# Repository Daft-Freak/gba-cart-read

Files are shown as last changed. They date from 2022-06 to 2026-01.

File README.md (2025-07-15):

# GBA Cartridge Reader

Hardware and software for an RP2xxx-based Game Boy and Game Boy Advance cartridge reader that presents the contents as a USB storage device.

## Board
- `board` contains the "v1" PGA2040-based GBA-only board
- `board-v4` contains the new RP2350-based design that also supports Game Boy carts and can _theoretically_ be expanded. (to be added when I make the fixed version)
- (v2/3 designs were never made. For completeness v2 added the Game Boy support, and v3 was a custom RP2040 design)

## Case

- "v1": https://www.printables.com/model/972096-gba-cartridge-reader-case

## Software
For the old RP2040-based boards, just build like any other pico-sdk based project. For the RP2350-based board configure with `cmake -DPICO_BOARD=pico2 -DPICO_RP2350A=0 [...]`.

### Tested GBA carts
 - 8K EEPROM
 - 32k SRAM
 - 64k flash
 - 128k flash

### Tested GB/GBC carts (v4)
 - No MBC
 - MBC1 (<= 512k ROM / 8k RAM)
 - MBC2
 - MBC3
 - MBC5
 - MBC7 (256 byte EEPROM)

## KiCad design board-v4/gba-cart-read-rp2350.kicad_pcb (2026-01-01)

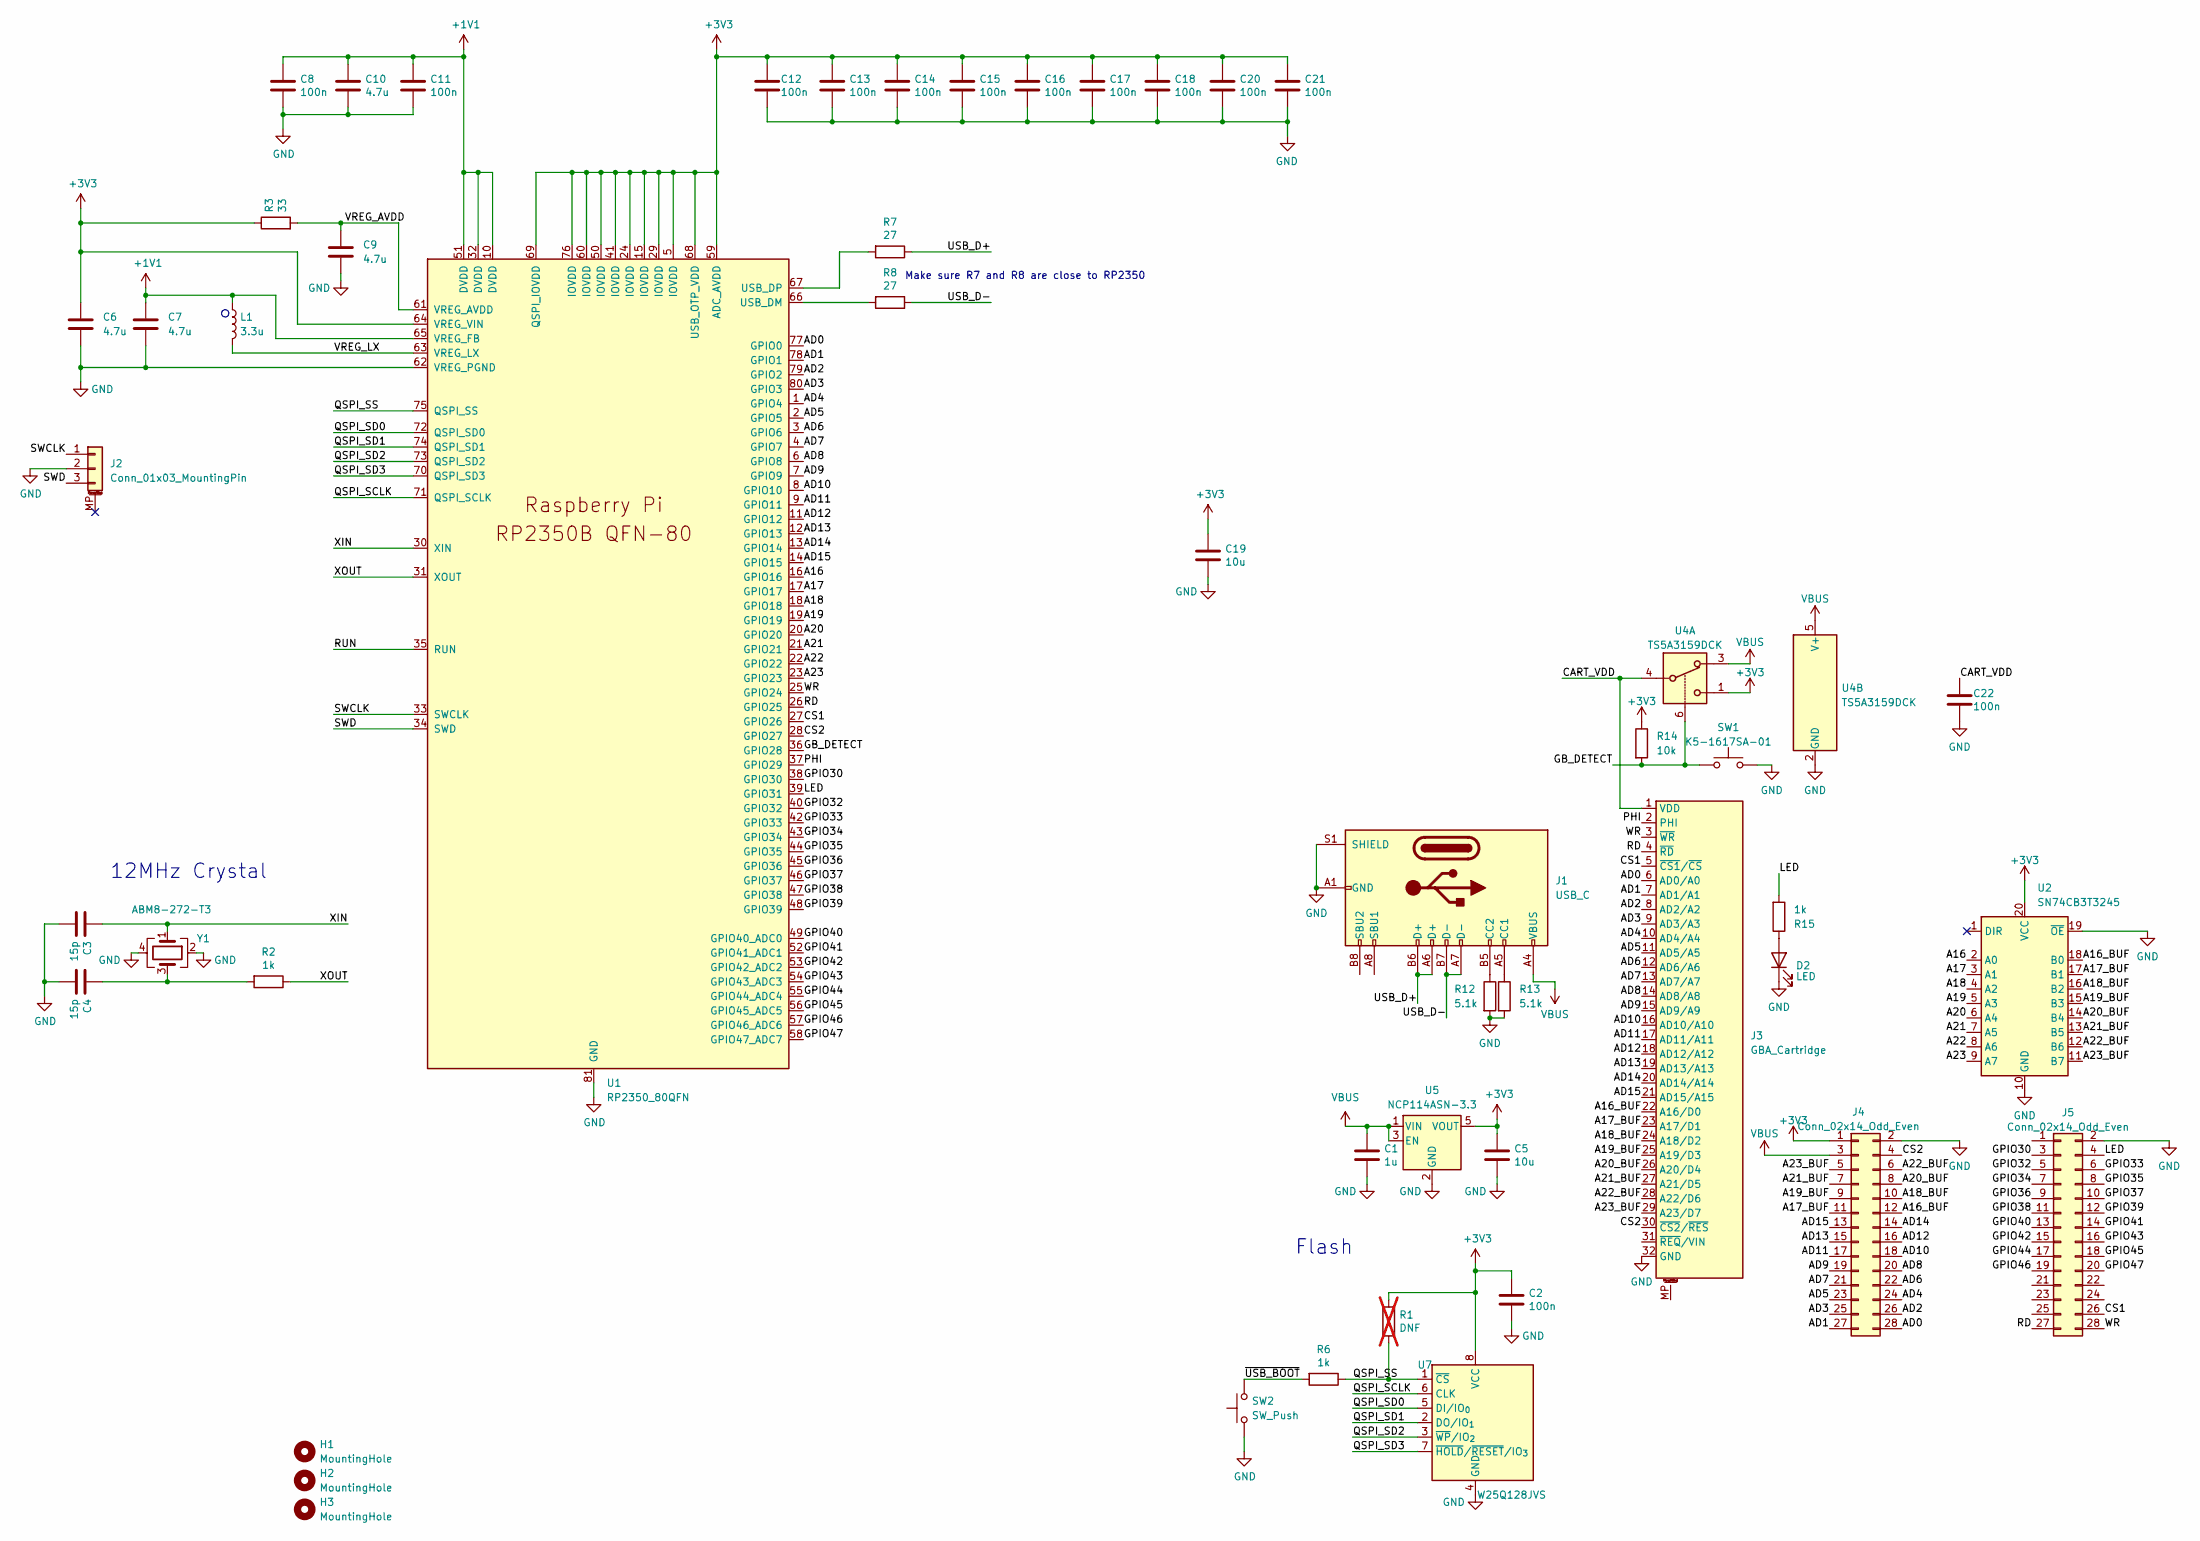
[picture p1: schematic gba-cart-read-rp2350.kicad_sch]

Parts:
C1: 1u; C_0805_2012Metric
C2, C8, C11, C12, C13, C14, C15, C16, C17, C18, C20, C21, C22: 100n; C_0402_1005Metric
C3, C4: 15p; C_0402_1005Metric
C5, C19: 10u; C_0805_2012Metric
C6, C7: 4.7u; C_0402_1005Metric_small_pads
C9, C10: 4.7u; C_0402_1005Metric
D2: LED; LED_0603_1608Metric
H1, H2, H3: MountingHole; MountingHole_2.7mm_M2.5
J1: USB_C; USB_C_Receptacle_HRO_TYPE-C-31-M-12
J2: Conn_01x03_MountingPin; JST_SH_SM03B-SRSS-TB_1x03-1MP_P1.00mm_Horizontal
J3: GBA_Cartridge; GameBoy_Cartridge_AGS_1x32-1MP_P1.50mm_Socket_Horizontal
J4, J5: Conn_02x14_Odd_Even; PinHeader_2x14_P2.54mm_Vertical
L1: 3.3u; L_pol_2016
R1: DNF; C_0402_1005Metric; not fitted
R2, R6, R15: 1k; R_0402_1005Metric
R3: 33; R_0402_1005Metric
R7, R8: 27; R_0402_1005Metric
R12, R13: 5.1k; R_0402_1005Metric
R14: 10k; R_0402_1005Metric
SW1: K5-1617SA-01
SW2: SW_Push; SW_Push_1P1T_XKB_TS-1187A
U1: RP2350_80QFN; RP2350-QFN-80-1EP_10x10_P0.4mm_EP3.4x3.4mm_ThermalVias
U2: SN74CB3T3245; TSSOP-20_4.4x6.5mm_P0.65mm
U4: TS5A3159DCK; SOT-363_SC-70-6
U5: NCP114ASN-3.3; TSOP-5_1.65x3.05mm_P0.95mm
U7: W25Q128JVS; SOIC-8_5.3x5.3mm_P1.27mm
Y1: ABM8-272-T3; Crystal_SMD_3225-4Pin_3.2x2.5mm

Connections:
+1V1: C7.1, C8.1, C10.1, C11.1, L1.1, U1.10 (DVDD), U1.32 (DVDD), U1.51 (DVDD), U1.65 (VREG_FB)
+3V3: C2.1, C5.1, C6.1, C12.1, C13.1, C14.1, C15.1, C16.1, C17.1, C18.1, C19.1, C20.1, C21.1, J4.1, R1.1, R3.1, R14.1, U1.5 (IOVDD), U1.15 (IOVDD), U1.24 (IOVDD), U1.29 (IOVDD), U1.41 (IOVDD), U1.50 (IOVDD), U1.59 (ADC_AVDD), U1.60 (IOVDD), U1.64 (VREG_VIN), U1.68 (USB_OTP_VDD), U1.69 (QSPI_IOVDD), U1.76 (IOVDD), U2.20 (VCC), U4.1, U5.5 (VOUT), U7.8 (VCC)
/A16: U1.16 (GPIO16), U2.2 (A0)
/A16_BUF: J3.22 (A16/D0), J4.12, U2.18 (B0)
/A17: U1.17 (GPIO17), U2.3 (A1)
/A17_BUF: J3.23 (A17/D1), J4.11, U2.17 (B1)
/A18: U1.18 (GPIO18), U2.4 (A2)
/A18_BUF: J3.24 (A18/D2), J4.10, U2.16 (B2)
/A19: U1.19 (GPIO19), U2.5 (A3)
/A19_BUF: J3.25 (A19/D3), J4.9, U2.15 (B3)
/A20: U1.20 (GPIO20), U2.6 (A4)
/A20_BUF: J3.26 (A20/D4), J4.8, U2.14 (B4)
/A21: U1.21 (GPIO21), U2.7 (A5)
/A21_BUF: J3.27 (A21/D5), J4.7, U2.13 (B5)
/A22: U1.22 (GPIO22), U2.8 (A6)
/A22_BUF: J3.28 (A22/D6), J4.6, U2.12 (B6)
/A23: U1.23 (GPIO23), U2.9 (A7)
/A23_BUF: J3.29 (A23/D7), J4.5, U2.11 (B7)
/AD0: J3.6 (AD0/A0), J4.28, U1.77 (GPIO0)
/AD1: J3.7 (AD1/A1), J4.27, U1.78 (GPIO1)
/AD2: J3.8 (AD2/A2), J4.26, U1.79 (GPIO2)
/AD3: J3.9 (AD3/A3), J4.25, U1.80 (GPIO3)
/AD4: J3.10 (AD4/A4), J4.24, U1.1 (GPIO4)
/AD5: J3.11 (AD5/A5), J4.23, U1.2 (GPIO5)
/AD6: J3.12 (AD6/A6), J4.22, U1.3 (GPIO6)
/AD7: J3.13 (AD7/A7), J4.21, U1.4 (GPIO7)
/AD8: J3.14 (AD8/A8), J4.20, U1.6 (GPIO8)
/AD9: J3.15 (AD9/A9), J4.19, U1.7 (GPIO9)
/AD10: J3.16 (AD10/A10), J4.18, U1.8 (GPIO10)
/AD11: J3.17 (AD11/A11), J4.17, U1.9 (GPIO11)
/AD12: J3.18 (AD12/A12), J4.16, U1.11 (GPIO12)
/AD13: J3.19 (AD13/A13), J4.15, U1.12 (GPIO13)
/AD14: J3.20 (AD14/A14), J4.14, U1.13 (GPIO14)
/AD15: J3.21 (AD15/A15), J4.13, U1.14 (GPIO15)
/CART_VDD: C22.1, J3.1 (VDD), U4.4
/CS1: J3.5 (~CS1/~CS), J5.26, U1.27 (GPIO26)
/CS2: J3.30 (~CS2/~RES), J4.4, U1.28 (GPIO27)
/GB_DETECT: R14.2, SW1.2, U1.36 (GPIO28), U4.6
/GPIO30: J5.3, U1.38 (GPIO30)
/GPIO32: J5.5, U1.40 (GPIO32)
/GPIO33: J5.6, U1.42 (GPIO33)
/GPIO34: J5.7, U1.43 (GPIO34)
/GPIO35: J5.8, U1.44 (GPIO35)
/GPIO36: J5.9, U1.45 (GPIO36)
/GPIO37: J5.10, U1.46 (GPIO37)
/GPIO38: J5.11, U1.47 (GPIO38)
/GPIO39: J5.12, U1.48 (GPIO39)
/GPIO40: J5.13, U1.49 (GPIO40_ADC0)
/GPIO41: J5.14, U1.52 (GPIO41_ADC1)
/GPIO42: J5.15, U1.53 (GPIO42_ADC2)
/GPIO43: J5.16, U1.54 (GPIO43_ADC3)
/GPIO44: J5.17, U1.55 (GPIO44_ADC4)
/GPIO45: J5.18, U1.56 (GPIO45_ADC5)
/GPIO46: J5.19, U1.57 (GPIO46_ADC6)
/GPIO47: J5.20, U1.58 (GPIO47_ADC7)
/LED: J5.4, R15.2, U1.39 (GPIO31)
/PHI: J3.2 (PHI), U1.37 (GPIO29)
/QSPI_SCLK: U1.71 (QSPI_SCLK), U7.6 (CLK)
/QSPI_SD0: U1.72 (QSPI_SD0), U7.5 (DI/IO_{0})
/QSPI_SD1: U1.74 (QSPI_SD1), U7.2 (DO/IO_{1})
/QSPI_SD2: U1.73 (QSPI_SD2), U7.3 (~WP/IO_{2})
/QSPI_SD3: U1.70 (QSPI_SD3), U7.7 (~HOLD/~RESET/IO_{3})
/QSPI_SS: R1.2, R6.1, U1.75 (QSPI_SS), U7.1 (~CS)
/RD: J3.4 (~RD), J5.27, U1.26 (GPIO25)
/RUN: U1.35 (RUN)
/SWCLK: J2.1, U1.33 (SWCLK)
/SWD: J2.3, U1.34 (SWD)
/USB_D+: J1.A6 (D+), J1.B6 (D+), R7.1
/USB_D-: J1.A7 (D-), J1.B7 (D-), R8.1
/VREG_AVDD: C9.1, R3.2, U1.61 (VREG_AVDD)
/VREG_LX: L1.2, U1.63 (VREG_LX)
/WR: J3.3 (~WR), J5.28, U1.25 (GPIO24)
/XIN: C3.1, U1.30 (XIN), Y1.1
/XOUT: R2.1, U1.31 (XOUT)
/~USB_BOOT: R6.2, SW2.2
GND: C1.2, C2.2, C3.2, C4.2, C5.2, C6.2, C7.2, C8.2, C9.2, C10.2, C11.2, C12.2, C13.2, C14.2, C15.2, C16.2, C17.2, C18.2, C19.2, C20.2, C21.2, C22.2, D2.1 (K), J1.A1 (GND), J1.A12 (GND), J1.B1 (GND), J1.B12 (GND), J1.S1 (SHIELD), J2.2, J3.32 (GND), J4.2, J5.2, R12.2, R13.2, SW1.1, SW2.1, U1.62 (VREG_PGND), U1.81 (GND), U2.10 (GND), U2.19 (~OE), U4.2 (GND), U5.2 (GND), U7.4 (GND), Y1.2, Y1.4
unnamed: C4.1, R2.2, Y1.3
unnamed: D2.2 (A), R15.1
unnamed: J1.A5 (CC1), R13.1
unnamed: J1.B5 (CC2), R12.1
unnamed: R8.2, U1.66 (USB_DM)
unnamed: R7.2, U1.67 (USB_DP)
VBUS: C1.1, J1.A4 (VBUS), J1.A9 (VBUS), J1.B4 (VBUS), J1.B9 (VBUS), J4.3, U4.3, U4.5 (V+), U5.1 (VIN), U5.3 (EN)

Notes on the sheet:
12MHz Crystal
Flash
Make sure R7 and R8 are close to RP2350

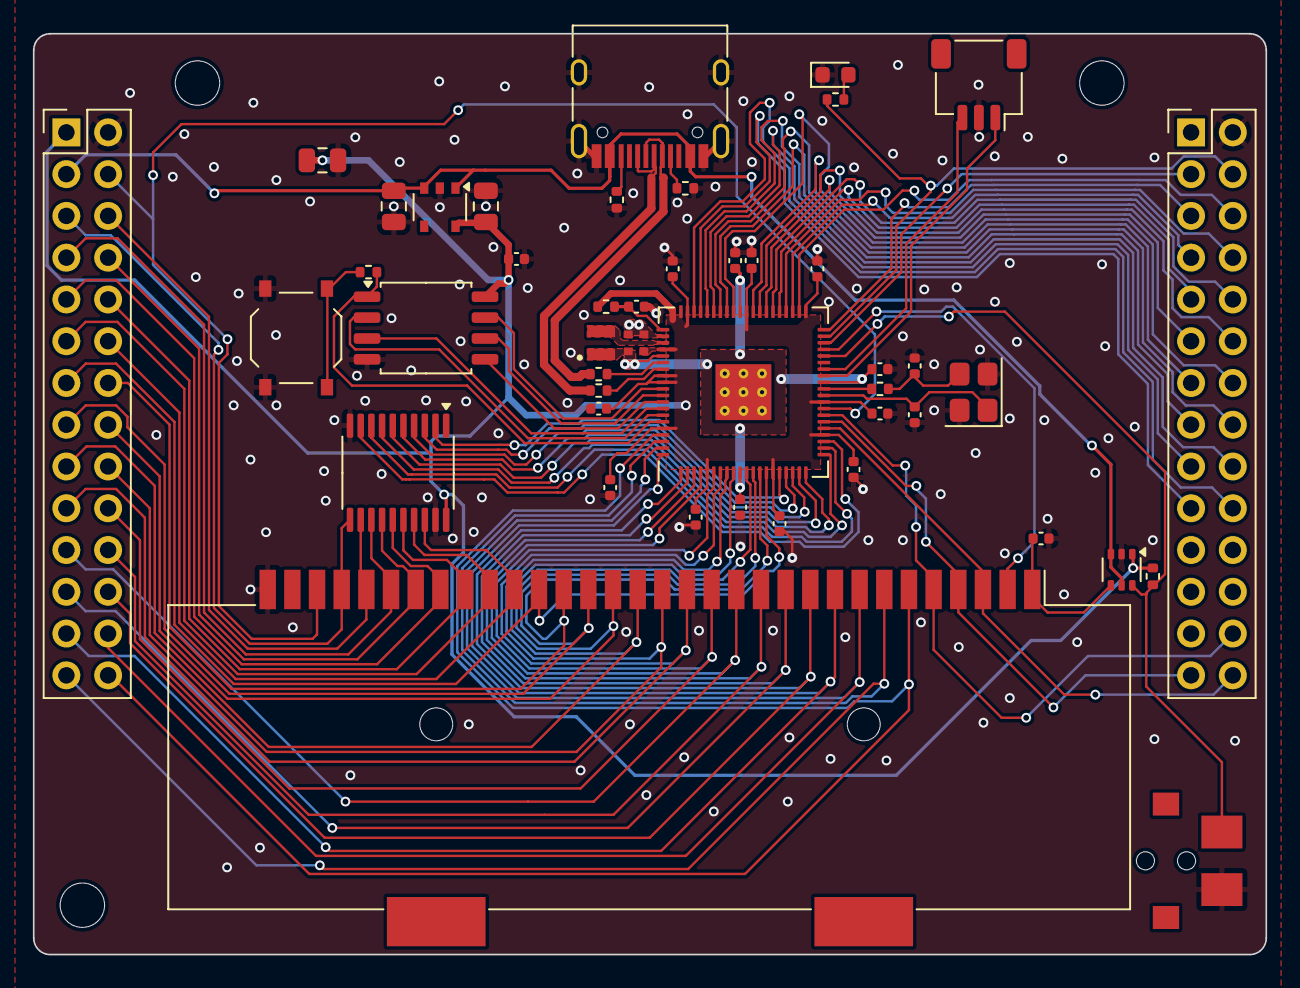
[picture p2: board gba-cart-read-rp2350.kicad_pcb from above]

Board: 2 copper layers, 75.0 x 56.0 mm, 49 parts (0 on the bottom side), 82 nets.

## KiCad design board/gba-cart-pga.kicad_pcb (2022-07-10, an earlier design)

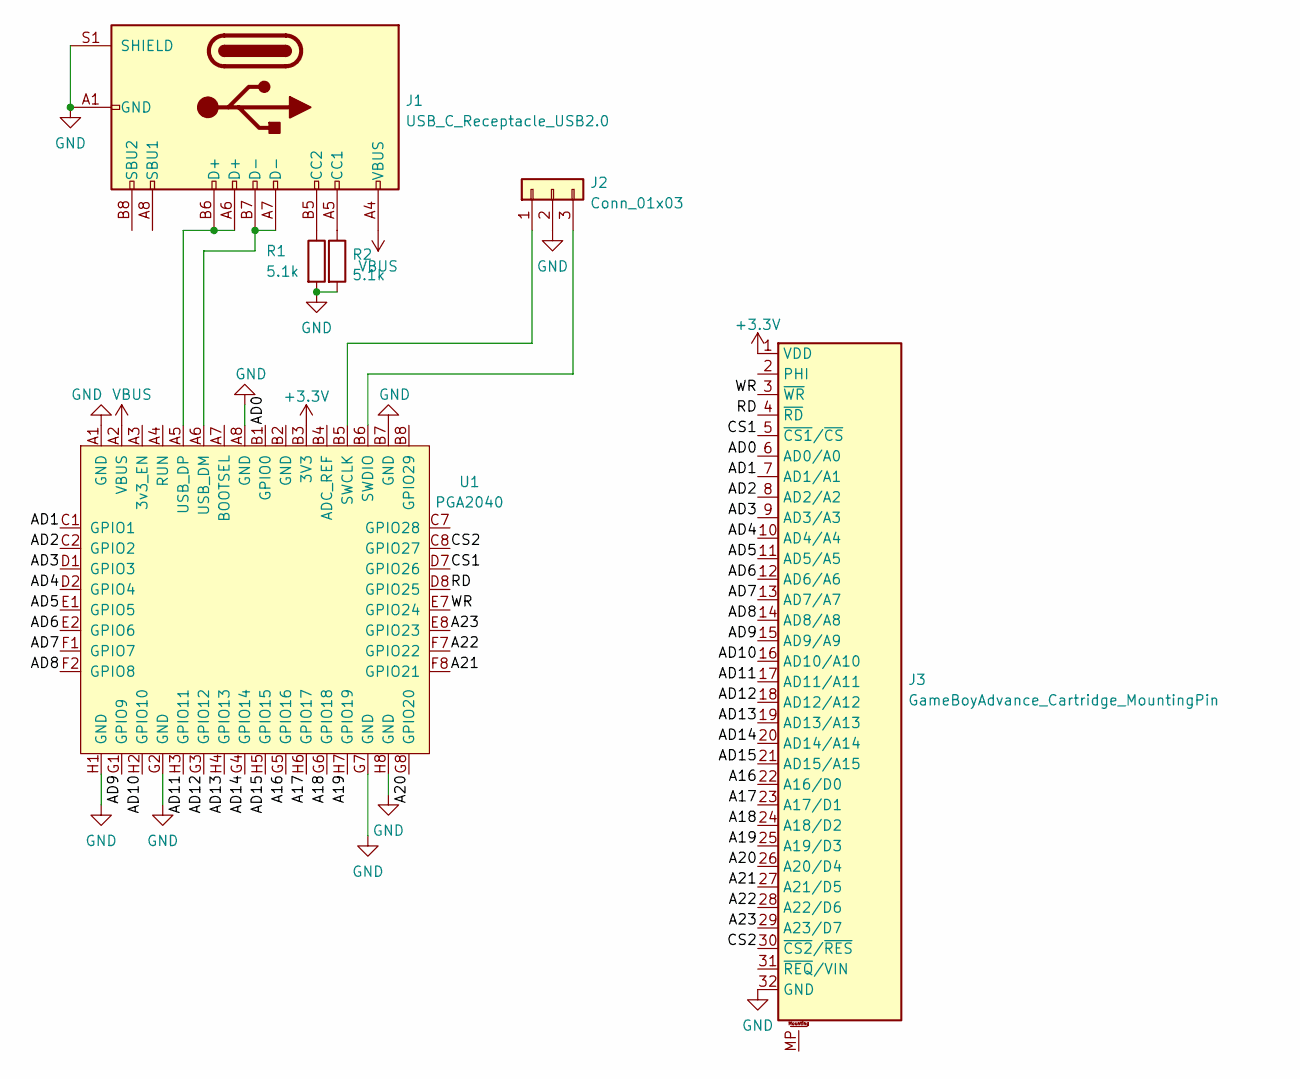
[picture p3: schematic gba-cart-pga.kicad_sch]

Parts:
J1: USB_C_Receptacle_USB2.0; USB_C_Receptacle_XKB_U262-16XN-4BVC11
J2: Conn_01x03; PinHeader_1x03_P2.54mm_Vertical
J3: GameBoyAdvance_Cartridge_MountingPin; GameBoy_Cartridge_AGS_1x32-1MP_P1.50mm_Socket_Horizontal
R1, R2: 5.1k; R_0805_2012Metric_Pad1.20x1.40mm_HandSolder
U1: PGA2040; PGA2040_PTH_NO_SLOT

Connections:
+3V3: J3.1 (VDD), U1.B3 (3V3)
/A16: J3.22 (A16/D0), U1.G5 (GPIO16)
/A17: J3.23 (A17/D1), U1.H6 (GPIO17)
/A18: J3.24 (A18/D2), U1.G6 (GPIO18)
/A19: J3.25 (A19/D3), U1.H7 (GPIO19)
/A20: J3.26 (A20/D4), U1.G8 (GPIO20)
/A21: J3.27 (A21/D5), U1.F8 (GPIO21)
/A22: J3.28 (A22/D6), U1.F7 (GPIO22)
/A23: J3.29 (A23/D7), U1.E8 (GPIO23)
/AD0: J3.6 (AD0/A0), U1.B1 (GPIO0)
/AD1: J3.7 (AD1/A1), U1.C1 (GPIO1)
/AD2: J3.8 (AD2/A2), U1.C2 (GPIO2)
/AD3: J3.9 (AD3/A3), U1.D1 (GPIO3)
/AD4: J3.10 (AD4/A4), U1.D2 (GPIO4)
/AD5: J3.11 (AD5/A5), U1.E1 (GPIO5)
/AD6: J3.12 (AD6/A6), U1.E2 (GPIO6)
/AD7: J3.13 (AD7/A7), U1.F1 (GPIO7)
/AD8: J3.14 (AD8/A8), U1.F2 (GPIO8)
/AD9: J3.15 (AD9/A9), U1.G1 (GPIO9)
/AD10: J3.16 (AD10/A10), U1.H2 (GPIO10)
/AD11: J3.17 (AD11/A11), U1.H3 (GPIO11)
/AD12: J3.18 (AD12/A12), U1.G3 (GPIO12)
/AD13: J3.19 (AD13/A13), U1.H4 (GPIO13)
/AD14: J3.20 (AD14/A14), U1.G4 (GPIO14)
/AD15: J3.21 (AD15/A15), U1.H5 (GPIO15)
/CS1: J3.5 (~CS1/~CS), U1.D7 (GPIO26)
/CS2: J3.30 (~CS2/~RES), U1.C8 (GPIO27)
/RD: J3.4 (~RD), U1.D8 (GPIO25)
/WR: J3.3 (~WR), U1.E7 (GPIO24)
GND: J1.A1 (GND), J1.A12 (GND), J1.B1 (GND), J1.B12 (GND), J1.S1 (SHIELD), J2.2, J3.32 (GND), R1.2, R2.2, U1.A1 (GND), U1.A8 (GND), U1.B7 (GND), U1.G2 (GND), U1.G7 (GND), U1.H1 (GND), U1.H8 (GND)
unnamed: J1.A5 (CC1), R2.1
unnamed: J1.A6 (D+), J1.B6 (D+), U1.A5 (USB_DP)
unnamed: J1.A7 (D-), J1.B7 (D-), U1.A6 (USB_DM)
unnamed: J1.B5 (CC2), R1.1
unnamed: J2.1, U1.B5 (SWCLK)
unnamed: J2.3, U1.B6 (SWDIO)
VBUS: J1.A4 (VBUS), J1.A9 (VBUS), J1.B4 (VBUS), J1.B9 (VBUS), U1.A2 (VBUS)

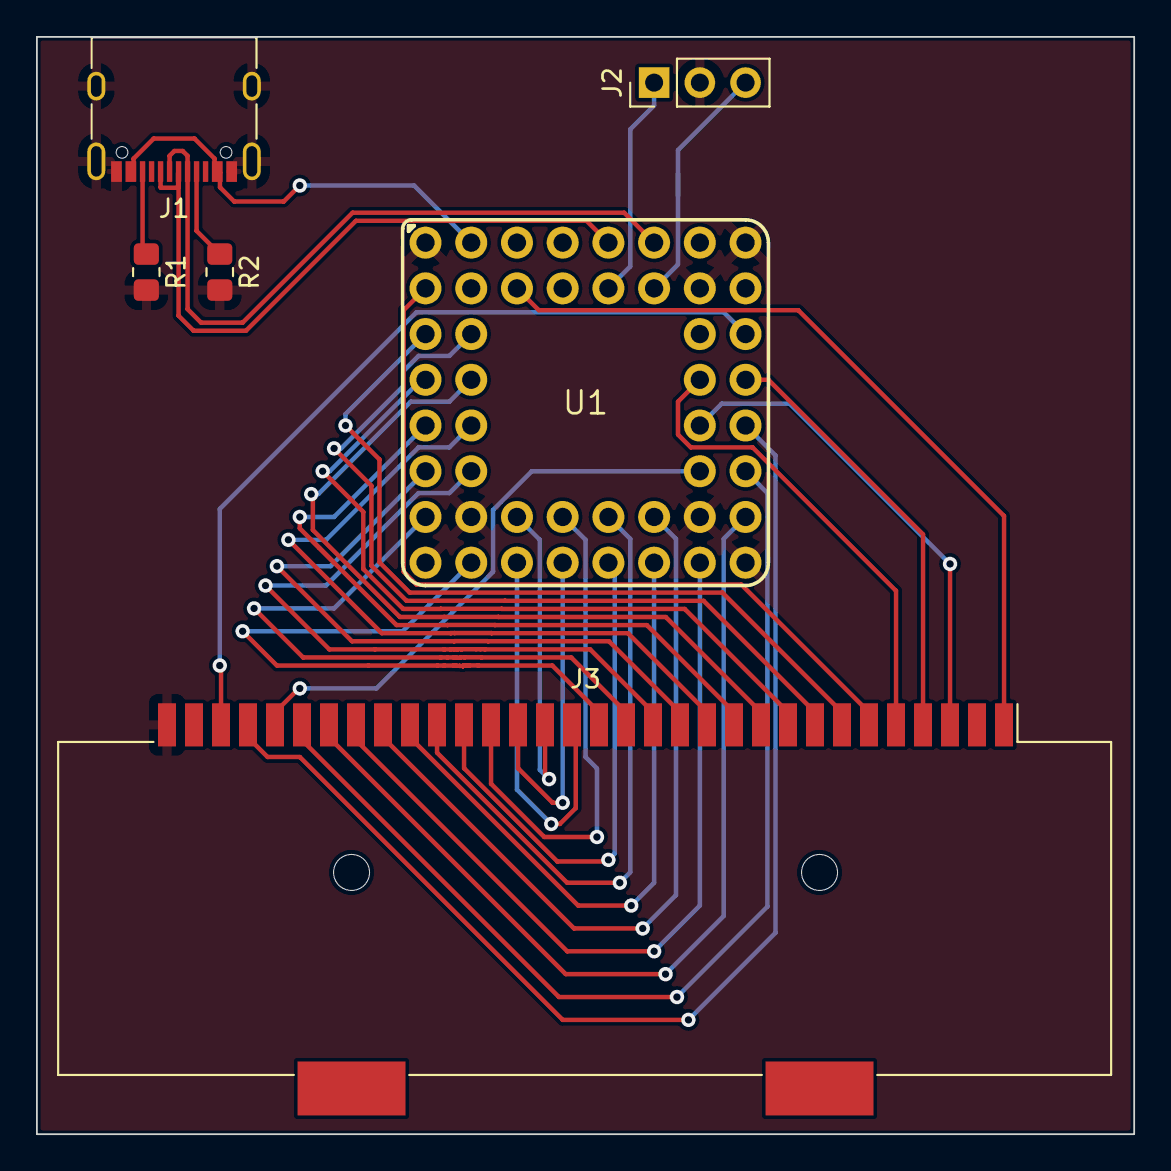
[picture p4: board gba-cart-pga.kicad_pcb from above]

Board: 2 copper layers, 61.0 x 61.0 mm, 6 parts (0 on the bottom side), 37 nets.

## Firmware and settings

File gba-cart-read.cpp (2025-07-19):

#include <algorithm>

#include "pico/stdlib.h"
#include "pico/time.h"
#include "tusb.h"

#include "cartridge.hpp"
#include "filesystem.hpp"

#ifdef PICO_RP2350
#define GB_DETECT_PIN 28
#define STATUS_LED_PIN 31
#endif

static char curGameCode[4]{0};

// GBA
static Cartridge::SaveType saveType = Cartridge::SaveType::Unknown;

// DMG
static Cartridge::MBCType mbcType = Cartridge::MBCType::None;

static void statusSet(bool value)
{
#ifdef STATUS_LED_PIN
    gpio_put(STATUS_LED_PIN, !value);
#endif
}

static void statusToggle()
{
#ifdef STATUS_LED_PIN
    gpio_xor_mask64(1 << STATUS_LED_PIN);
#endif
}

static absolute_time_t ABSOLUTE_TIME_INITIALIZED_VAR(lastAccessBlinkTime, 0);

static void blinkLEDForAccess()
{
    auto time = get_absolute_time();
    if(absolute_time_diff_us(lastAccessBlinkTime, time) > 80000)
    {
        statusToggle();
        lastAccessBlinkTime = time;
    }
}

static void readDMGROM(uint32_t offset, uint32_t len, uint8_t *buf)
{
    // blink while reading
    blinkLEDForAccess();

    if(mbcType == Cartridge::MBCType::None)
        Cartridge::readDMG(offset, buf, len);
    else if(mbcType == Cartridge::MBCType::MBC1)
        Cartridge::readMBC1ROM(offset, buf, len);
    else if(mbcType == Cartridge::MBCType::MBC2)
        Cartridge::readMBC2ROM(offset, buf, len);
    else if(mbcType == Cartridge::MBCType::MBC3)
        Cartridge::readMBC3ROM(offset, buf, len);
    else if(mbcType == Cartridge::MBCType::MBC5)
        Cartridge::readMBC5ROM(offset, buf, len);
    else if(mbcType == Cartridge::MBCType::MBC7)
        Cartridge::readMBC7ROM(offset, buf, len);
}

static void readDMGRAM(uint32_t offset, uint32_t len, uint8_t *buf)
{
    // blink while reading
    blinkLEDForAccess();

    if(mbcType == Cartridge::MBCType::MBC1)
        Cartridge::readMBC1RAM(offset, buf, len);
    else if(mbcType == Cartridge::MBCType::MBC2)
        Cartridge::readMBC2RAM(offset, buf, len);
    else if(mbcType == Cartridge::MBCType::MBC3)
        Cartridge::readMBC3RAM(offset, buf, len);
    else if(mbcType == Cartridge::MBCType::MBC5)
        Cartridge::readMBC5RAM(offset, buf, len);
    else if(mbcType == Cartridge::MBCType::MBC7)
        Cartridge::readMBC7EEPROM(offset, buf, len);
}

static void readROM(uint32_t offset, uint32_t len, uint8_t *buf)
{
    // might have to split this to not wrap the address
    // (assuming nothing ever tries to read > 64k halfwords)
    auto maxLen = 0x20000 - (offset & 0x1FFFF);

    // blink while reading
    blinkLEDForAccess();

    Cartridge::readROM(offset, reinterpret_cast<uint16_t *>(buf), std::min(len, maxLen) / 2);

    if(maxLen < len)
        Cartridge::readROM(offset + maxLen, reinterpret_cast<uint16_t *>(buf + maxLen), (len - maxLen) / 2);
}

static void readSave(uint32_t offset, uint32_t len, uint8_t *buf)
{
    // blink while reading
    blinkLEDForAccess();

    if(saveType == Cartridge::SaveType::EEPROM_512)
        Cartridge::readEEPROMSave(offset, reinterpret_cast<uint64_t *>(buf), len / 8, false);
    else if(saveType == Cartridge::SaveType::EEPROM_8K)
        Cartridge::readEEPROMSave(offset, reinterpret_cast<uint64_t *>(buf), len / 8, true);
    else if(saveType == Cartridge::SaveType::Flash_128K)
        Cartridge::readFlashSave(offset, buf, len);
    else
        Cartridge::readRAMSave(offset, buf, len); // this is okay for 64k flash
}

int main()
{
    Cartridge::initIO();

#ifdef STATUS_LED_PIN
    gpio_init(STATUS_LED_PIN);
    gpio_set_dir(STATUS_LED_PIN, true);
#endif

#ifdef GB_DETECT_PIN
    gpio_init(GB_DETECT_PIN);
    gpio_set_dir(GB_DETECT_PIN, false);
#endif

    tusb_init();

    stdio_init_all();

    // wait to be mounted before scanning for cart
    while(!tud_mounted()) tud_task();

    statusSet(false);

    uint32_t lastCheckTime = 0;
    uint32_t lastBlinkTime = 0;

    bool gbDetected = false;

    while(true)
    {
        tud_task();

        auto curTime = to_ms_since_boot(get_absolute_time());

        // check more frequently if no cart
        bool validGame = curGameCode[0] != 0;
        uint32_t interval = !validGame ? 100 : 1000;

        // cart detection polling
        if(curTime - lastCheckTime > interval)
        {
#ifdef GB_DETECT_PIN
            gbDetected = !gpio_get(GB_DETECT_PIN);
#endif
            // blink LED if searching
            if(!validGame && curTime - lastBlinkTime >= 500)
            {
                statusToggle();
                lastBlinkTime = curTime;
            }

            uint32_t romSize = 0;

            if(!gbDetected) // !GB == GBA
            {
                auto header = Cartridge::readGBAHeader();


                if(header.checksumValid)
                {
                    // valid header, check if cart is changing
                    if(memcmp(curGameCode, header.gameCode, 4) != 0)
                    {
                        // update cart size
                        memcpy(curGameCode, header.gameCode, 4);
            
                        romSize = Cartridge::getGBAROMSize();
                        uint32_t saveSize = 0;
                        saveType = Cartridge::getSaveType(romSize);

                        switch(saveType)
                        {
                            case Cartridge::SaveType::Unknown:
                                break;
                            case Cartridge::SaveType::EEPROM_512:
                                saveSize = 512; break;
                            case Cartridge::SaveType::EEPROM_8K:
                                saveSize = 8 * 1024; break;
                            case Cartridge::SaveType::RAM:
                                saveSize = 32 * 1024; break;
                            case Cartridge::SaveType::Flash_64K:
                                saveSize = 64 * 1024; break;
                            case Cartridge::SaveType::Flash_128K:
                                saveSize = 128 * 1024; break;
                        }

                        Filesystem::setTargetSize(romSize + saveSize);

                        Filesystem::resetFiles();

                        char longName[32];
                        snprintf(longName, 32, "%s.gba", header.title);

                        Filesystem::addFile(0, romSize, longName, readROM);

                        if(saveSize)
                        {
                            snprintf(longName, 32, "%s.sav", header.title);
                            Filesystem::addFile(romSize, saveSize, longName, readSave);
                        }
                    }
                    else
                    {
                        // same game, don't reset
                        lastCheckTime = curTime;
                        continue;
                    }
                }
            }
            else // GB
            {
                auto header = Cartridge::readDMGHeader();

                if(header.checksumValid)
                {
                    romSize = Cartridge::getDMGROMSize(header);
                    uint32_t ramSize = Cartridge::getDMGRAMSize(header);
                    mbcType = Cartridge::getMBCType(header);

                    if(memcmp(curGameCode, header.title, 4) != 0)
                    {
                        Filesystem::setTargetSize(romSize + ramSize);

                        Filesystem::resetFiles();

                        // use lowercase for long names
                        char longName[32];
                        snprintf(longName, 32, "%s.%s", header.title, header.cgbSupport ? "gbc" : "gb");

                        // title will get truncated to 8 chars in short name
                        Filesystem::addFile(0, romSize, longName, readDMGROM);

                        if(ramSize)
                        {
                            snprintf(longName, 32, "%s.sav", header.title);
                            Filesystem::addFile(romSize, ramSize, longName, readDMGRAM);
                        }
                    }

                    memcpy(curGameCode, header.title, 4);
                }
            }

            // keep lit if valid
            if(curGameCode[0] != 0 && !validGame)
                statusSet(true);
            
            if(!romSize)
            {
                memset(curGameCode, 0, 4);
                Filesystem::setTargetSize(0);
            }

            lastCheckTime = curTime;
        }

        // restore LED after access
        if(curGameCode[0] != 0 && absolute_time_diff_us(lastAccessBlinkTime, get_absolute_time()) > 1000000)
            statusSet(true);
    }

    return 0;
}

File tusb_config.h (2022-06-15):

/*
 * The MIT License (MIT)
 *
 * Copyright (c) 2019 Ha Thach (tinyusb.org)
 *
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
 */

#ifndef _TUSB_CONFIG_H_
#define _TUSB_CONFIG_H_

#ifdef __cplusplus
 extern "C" {
#endif

//--------------------------------------------------------------------
// COMMON CONFIGURATION
//--------------------------------------------------------------------

// defined by board.mk
#ifndef CFG_TUSB_MCU
  #error CFG_TUSB_MCU must be defined
#endif

// RHPort number used for device can be defined by board.mk, default to port 0
#ifndef BOARD_DEVICE_RHPORT_NUM
  #define BOARD_DEVICE_RHPORT_NUM     0
#endif

// RHPort max operational speed can defined by board.mk
// Default to Highspeed for MCU with internal HighSpeed PHY (can be port specific), otherwise FullSpeed
#ifndef BOARD_DEVICE_RHPORT_SPEED
  #if (CFG_TUSB_MCU == OPT_MCU_LPC18XX || CFG_TUSB_MCU == OPT_MCU_LPC43XX || CFG_TUSB_MCU == OPT_MCU_MIMXRT10XX || \
       CFG_TUSB_MCU == OPT_MCU_NUC505  || CFG_TUSB_MCU == OPT_MCU_CXD56)
    #define BOARD_DEVICE_RHPORT_SPEED   OPT_MODE_HIGH_SPEED
  #else
    #define BOARD_DEVICE_RHPORT_SPEED   OPT_MODE_FULL_SPEED
  #endif
#endif

// Device mode with rhport and speed defined by board.mk

#if   BOARD_DEVICE_RHPORT_NUM == 0
  #define CFG_TUSB_RHPORT0_MODE     (OPT_MODE_DEVICE | BOARD_DEVICE_RHPORT_SPEED)
#elif BOARD_DEVICE_RHPORT_NUM == 1
  #define CFG_TUSB_RHPORT1_MODE     (OPT_MODE_DEVICE | BOARD_DEVICE_RHPORT_SPEED)
#else
  #error "Incorrect RHPort configuration"
#endif

// This example doesn't use an RTOS
#ifndef CFG_TUSB_OS
#define CFG_TUSB_OS               OPT_OS_NONE
#endif

// CFG_TUSB_DEBUG is defined by compiler in DEBUG build
// #define CFG_TUSB_DEBUG           0

/* USB DMA on some MCUs can only access a specific SRAM region with restriction on alignment.
 * Tinyusb use follows macros to declare transferring memory so that they can be put
 * into those specific section.
 * e.g
 * - CFG_TUSB_MEM SECTION : __attribute__ (( section(".usb_ram") ))
 * - CFG_TUSB_MEM_ALIGN   : __attribute__ ((aligned(4)))
 */
#ifndef CFG_TUSB_MEM_SECTION
#define CFG_TUSB_MEM_SECTION
#endif

#ifndef CFG_TUSB_MEM_ALIGN
#define CFG_TUSB_MEM_ALIGN          __attribute__ ((aligned(4)))
#endif

//--------------------------------------------------------------------
// DEVICE CONFIGURATION
//--------------------------------------------------------------------

#ifndef CFG_TUD_ENDPOINT0_SIZE
#define CFG_TUD_ENDPOINT0_SIZE    64

//------------- CLASS -------------//
#define CFG_TUD_CDC              1
#define CFG_TUD_MSC              1
#define CFG_TUD_HID              0
#define CFG_TUD_MIDI             0
#define CFG_TUD_VENDOR           0

// CDC FIFO size of TX and RX
#define CFG_TUD_CDC_RX_BUFSIZE   (TUD_OPT_HIGH_SPEED ? 512 : 64)
#define CFG_TUD_CDC_TX_BUFSIZE   (TUD_OPT_HIGH_SPEED ? 512 : 64)

// CDC Endpoint transfer buffer size, more is faster
#define CFG_TUD_CDC_EP_BUFSIZE   (TUD_OPT_HIGH_SPEED ? 512 : 64)

// MSC Buffer size of Device Mass storage
#define CFG_TUD_MSC_EP_BUFSIZE   4096
#endif

#ifdef __cplusplus
 }
#endif

#endif /* _TUSB_CONFIG_H_ */

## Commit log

2022-06-15 Initial commit
    Reads cart as a block device at ~340kB/s. USB code borrowed from 32blit-sdk.
2022-06-16 Rework FS to handle multiple files
    ... and allow names
    [gba-cart-read.cpp]
2022-06-16 Pass a callback for file reads
    Now we can _really_ handle multiple files... and the FS code doesn't need to see the cart code
    [gba-cart-read.cpp]
2022-06-16 Fix the 64k range assert
    [cartridge.cpp]
2022-06-16 Allow reading 64K flash saves
    This just works (helps if you don't test with a broken emulator)
    [gba-cart-read.cpp]
2022-06-16 Handle 128K flash saves
    Requires writes for bank switching
2022-06-18 Optimise PIO program
    Avoid nops for sideset, pack address/count, push values for dir changes and enable autopull
    13 -> 6 instructions
    [cartridge.cpp]
2022-06-18 Fix the range assert more
    [cartridge.cpp]
2022-06-18 Don't assign RAM CS to PIO
    It's not used and probably won't be. This also means we're not using all of the sideset bits
    [cartridge.cpp]
2022-06-20 Reorder PIO setup
    Push data before clearing the stall flag and enabling.
    [cartridge.cpp]
2022-06-20 Use DMA for rom reads
    Avoids stalling at a bad time and allows reducing the clock div again (not that it improves much over USB...)
    [cartridge.cpp]
2022-06-21 Use DMA bswap
    Uh, I forgot this was a thing
2022-06-22 WIP code for DMG carts
    Don't have the right hw to do this properly (no detection or voltage switching)
2022-07-10 Add PCB
    [gba-cart-pga-B_Cu.gbr, gba-cart-pga-B_Mask.gbr, gba-cart-pga-B_Paste.gbr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]
2023-10-04 gitignore for pcb
2023-10-04 Remove custon debug printint
2023-10-04 Avoid getting stuck in an insert/remove loop when cart doesn't change
    How long has this been broken?
    [gba-cart-read.cpp]
2023-10-04 Sprinkle some extra volatile on things
    Trying to fix most of getSaveType being optimised out... this doesn't do it
    [cartridge.cpp]
2023-10-04 Wait for mount before doing anything
    The save scan is still too slow to be doing during enumeration
    [gba-cart-read.cpp]
2025-07-01 Some LED blinking for the new board
2025-07-01 Use GB cart detection pin for the new board
    It still doesn't work though
    [gba-cart-read.cpp]
2025-07-02 Buffer direction hackery for the new board
    Using RD directly to control direction didin't seem to work, so I cut it and now we're only using the "override"
2025-07-02 Avoid repeatedly adding and removing gameboy cart
    [gba-cart-read.cpp]
2025-07-02 Wire up MBC1 ROM reading
2025-07-02 Wire up RAM for DMG carts
2025-07-05 Wire up MBC5
2025-07-10 gAdd some more delays to GBA RAM writing to (hopefully) fix reading 128k flash
    [cartridge.cpp]
2025-07-10 Wire up MBC2 reading
2025-07-11 Do MBC RAM banck switching before enabling RAM
    This feels safer
2025-07-11 Be more careful in writeDMG
    Doesn't fix the save corruption problems, but also doesn't hurt?
    [cartridge.cpp]
2025-07-12 Move IO init as early as possible
    Seems to be safer for not corrupting saves, so long as the cartridge is connected before power...
2025-07-13 Revert one of the delays in writeDMG
    Not that the CS stuff is fixed
    [cartridge.cpp]
2025-07-14 Add helper for PIO program switch
2025-07-14 Avoid redundant program changes
    Probably not a massive performance concern but still
    [cartridge.cpp]
2025-07-15 Wire up MBC7
2026-01-01 Add the V4 board files
    I already listed them in the readme. Note that this is the revised bersion that doesn't need DIR_OVERRIDE_PIN
    [gba-cart-read-rp2350.kicad_pcb, gba-cart-read-rp2350.kicad_sch]
